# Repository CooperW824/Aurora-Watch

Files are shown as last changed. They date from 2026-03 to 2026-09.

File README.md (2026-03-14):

# Aurora-Watch
Project Aurora: The most over-engineered gimmick ever. A watch that is a compass, thermometer, step-counter, flashlight, all with a rechargable battery, and a processor 50x faster than the Apollo Guidance Computer.

## What is it?

It is a custom designed printed circuit board that contains a ring of 12 RGB LEDs, a microcontroller, and some senors to:
1. Display the current time. Where the red LED represents the hour hand, the green LED is the minute hand and the blue LED is the second hand.
2. Display the current ambient temperature using the number of LEDs lit and the color of the LEDs for the temperature.
3. A magnetic compass with the red LED pointing north, and the blue LED pointing south
4. A read out of the current battery charge using the LEDs
5. A built in step counter
5. A flashlight that uses the red LEDs to create a red-light flashlight
6. Rechargable LiPO battery using USB-C

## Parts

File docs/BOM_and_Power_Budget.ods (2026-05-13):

Component Function | Component Name | Predicted Power Draw (uA) | BOM Cost | Notes | I2C Address
12x LEDs | EAST1616RGBA8 | 650 | $2.63
Microcontroller | STM32U031K8U6 | 83.8 | $4.50
Compass Module | LSM303AGR | 7.7 | $3.41 |  | 0b0011001 / 0b0011110
LED Controller | IS31FL3237 | 0 | $2.81 | (Included in LEDs) | 0b0110100
Temperature Sensor | TMP1075 | 1 | $0.20 |  | 0b1001000
Battery Charge Controller | BQ25185 | 4.5 | $1.93
USB to UART | CP2102N-A02-GQFN20R | 0 | $1.88 | (Only Active When Plugged In)
Battery Fuel Gauge | MAX17048G+T10 | 4 | $2.45 |  | 0b0110110
32.768KHz Crystal | ABS07-32.768KHZ-T | 1 | $0.50
Buck-Boost Converter | TPS63900 | 1 | $1.41
Passives |  | 10 | $6.00
 |  | 763 | $27.72 | Subtotal
 |  | Battery | $7.00
 |  | Board | $3.00
 |  |  | $37.72 | Per Watch
 |  | 2 MOQ | $75.44
 |  | Assembly | $25.00
 |  | Shipping | $40.00
 |  |  | $140.44 | Total

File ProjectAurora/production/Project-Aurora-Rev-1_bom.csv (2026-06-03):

Designator | Footprint | Quantity | Value | LCSC Part #
3V3, GND1, SWCLK1, SWDIO1 | TestPoint_Pad_2.0x2.0mm | 4 | TestPoint
B1, B10, B11, B12, B2, B3, B4, B5, B6, B8, B9, CHARGE_EN1, CHG_ST1, CHG_ST2, CP_RST1, CP_VBUS1, G1, G10, G11, G12, G2, G3, G4, G5, G6, G7, G8, G9, GND2, GND3, GND4, GND5, I2C_SCL1, I2C_SDA1, LB1, LED_SHUT1, MAG_INT1, NRST1, RB1, RED1, RED10, RED11, RED12, RED2, RED3, RED4, RED5, RED6, RED7, RED8, RED9, SOC_ALRT1, UART1_RX1, UART1_TX1, VBAT1, VBUS1, VDC1, XLI2, XLI_1 | TestPoint_Pad_1.0x1.0mm | 59 | TestPoint
B7 | TestPoint_Pad_1.0x1.0mm | 1 | `
BT1 | JST_SH_SM02B-SRSS-TB_1x02-1MP_P1.00mm_Horizontal | 1 | Battery_Cell
C1, C2 | 0603 | 2 | 18pF
C10, C13, C15, C18, C23, C26, C3, C4, C8 | 0603 | 9 | 0.1uF
C11, C12, C5 | 0603 | 3 | 4.7uF
C14, C20, C21, C7 | 0603 | 4 | 1uF
C16, C6 | 0603 | 2 | 0.01uF
C17, C22, C24 | 0603 | 3 | 10uF
C19 | 0603 | 1 | 220nF
C25 | 0603 | 1 | 22uF
C9 | 0603 | 1 | 4.7nF
D1, D10, D11, D12, D2, D3, D4, D5, D6, D7, D8, D9 | XL-1615RGBC-YG | 12 | LED_RGBA
D13, D14 | 0603 | 2 | LED
IC1 | IS31FL3237QFLS4TR | 1 | IS31FL3237-QFLS4-TR
IC2 | LGA-12_2x2mm_P0.5mm | 1 | LSM303AGRTR
IC3 | Texas_DLH0010A_WSON-10-1EP_2.2x2mm_P0.4mm_EP0.9x1.5mm_ThermalVias | 1 | BQ25185DLHR
IC4 | TDFN-8-1EP_2x2mm_P0.5mm_EP0.8x1.2mm | 1 | MAX17048G+T10
IC5 | WSON-10-1EP_2.5x2.5mm_P0.5mm_EP1.2x2mm | 1 | TPS63900DSKR
J1 | USB_C_Receptacle_GCT_USB4105-xx-A_16P_TopMnt_Horizontal | 1 | USB_C_Receptacle_USB2.0_14P
L1 | L_Coilcraft_0805HQ_2012Metric | 1 | 2.2uH
R1, R2, R21 | 0603 | 3 | 10K
R10, R9 | 0603 | 2 | 220
R11 | 0603 | 1 | 3.3K
R12 | 0603 | 1 | 100K
R14 | 0603 | 1 | 18K
R15 | 0603 | 1 | 2K
R18 | 0603 | 1 | 36.5K
R3, R4 | 0603 | 2 | 5.1K
R5 | 0603 | 1 | 1K
R6 | 0603 | 1 | 22.1K
R7 | 0603 | 1 | 47.5K
R8 | 0603 | 1 | 1M
S1, S2 | EVPAA202K | 2 | EVP-AA202K
TH1 | 0603 | 1 | 10K @ 25C, B=3435K
U1 | QFN-32-1EP_5x5mm_P0.5mm_EP3.45x3.45mm | 1 | STM32U031K8Ux
U2 | SiliconLabs_QFN-20-1EP_3x3mm_P0.5mm_EP1.8x1.8mm | 1 | CP2102N-Axx-xQFN20
U3 | Texas_DRT-3 | 1 | TPD2EUSB30A
U4 | WSON-8-1EP_2x2mm_P0.5mm_EP0.9x1.6mm_ThermalVias | 1 | TMP1075DSG
Y1 | ABS07 | 1 | ABS07-32.768KHZ-T

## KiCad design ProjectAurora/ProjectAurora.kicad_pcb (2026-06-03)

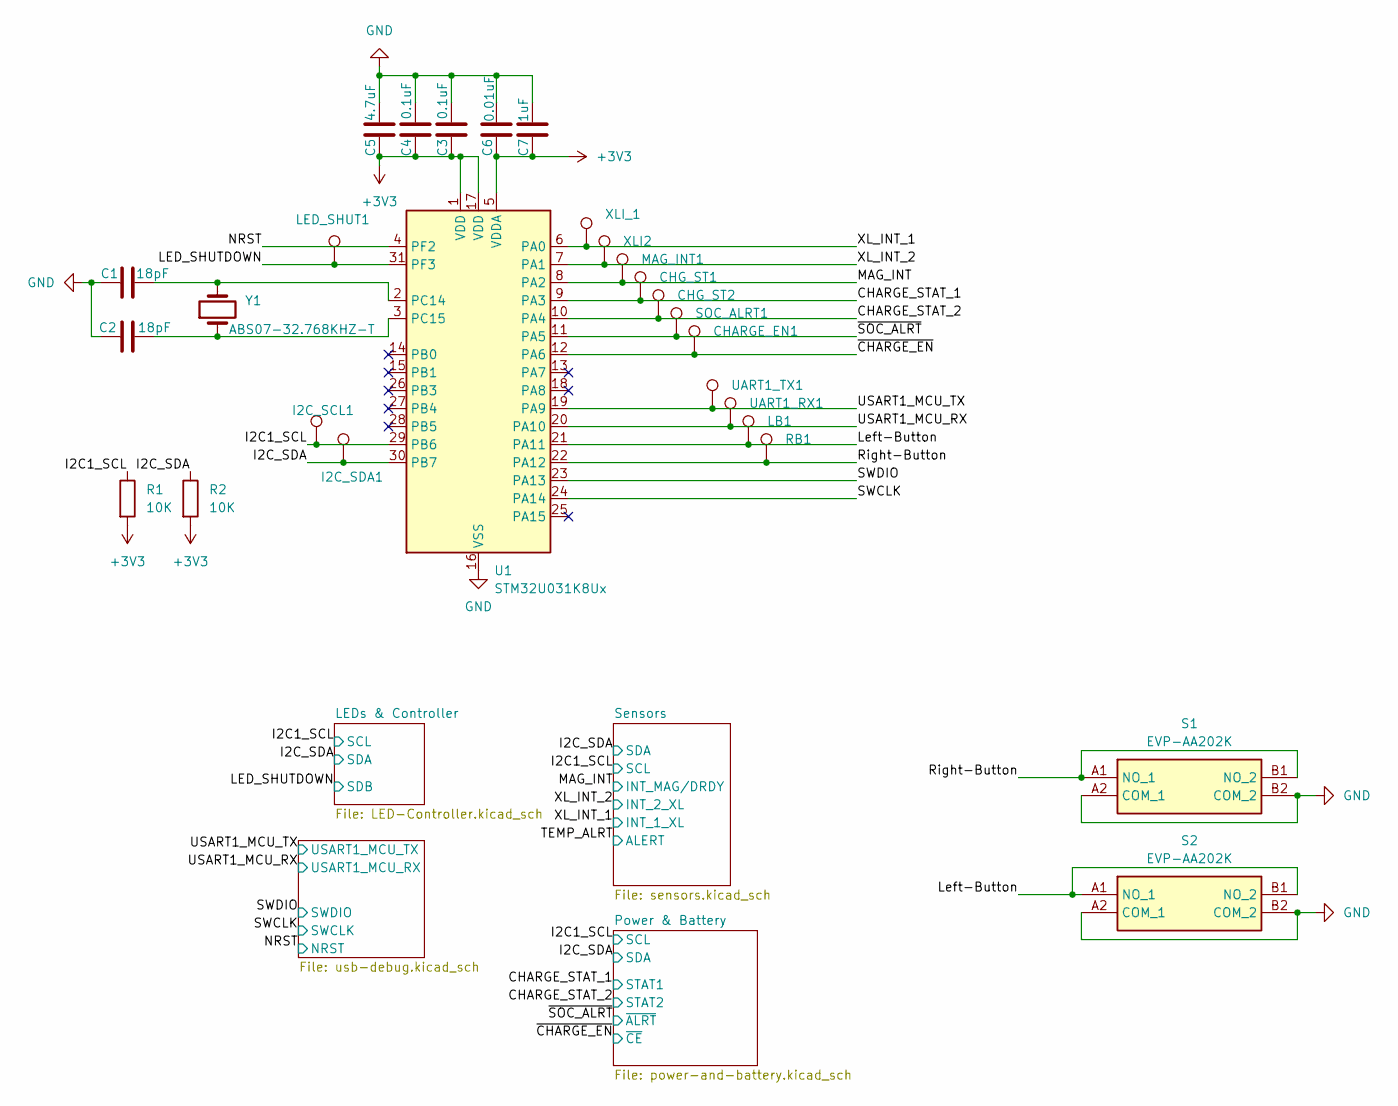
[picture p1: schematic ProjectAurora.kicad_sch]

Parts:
C1, C2: 18pF; C_0603_1608Metric
C3, C4: 0.1uF; C_0603_1608Metric
C5: 4.7uF; C_0603_1608Metric
C6: 0.01uF; C_0603_1608Metric
C7: 1uF; C_0603_1608Metric
CHARGE_EN1: TestPoint; TestPoint_Pad_1.0x1.0mm
CHG_ST1, CHG_ST2: TestPoint; TestPoint_Pad_1.0x1.0mm
I2C_SCL1, I2C_SDA1: TestPoint; TestPoint_Pad_1.0x1.0mm
LB1: TestPoint; TestPoint_Pad_1.0x1.0mm
LED_SHUT1: TestPoint; TestPoint_Pad_1.0x1.0mm
MAG_INT1: TestPoint; TestPoint_Pad_1.0x1.0mm
R1, R2: 10K; R_0603_1608Metric
RB1: TestPoint; TestPoint_Pad_1.0x1.0mm
S1, S2: EVP-AA202K; EVPAA202K; Mouser Part Number 667-EVP-AA202K
SOC_ALRT1: TestPoint; TestPoint_Pad_1.0x1.0mm
U1: STM32U031K8Ux; QFN-32-1EP_5x5mm_P0.5mm_EP3.45x3.45mm
UART1_RX1, UART1_TX1: TestPoint; TestPoint_Pad_1.0x1.0mm
XLI2: TestPoint; TestPoint_Pad_1.0x1.0mm
XLI_1: TestPoint; TestPoint_Pad_1.0x1.0mm
Y1: ABS07-32.768KHZ-T; ABS07

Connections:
+3V3: C3.1, C4.1, C5.1, C6.1, C7.1, R1.2, R2.2, U1.1 (VDD), U1.5 (VDDA), U1.17 (VDD); also elsewhere on the board
/CHARGE_STAT_1: CHG_ST1.1, U1.9 (PA3); also elsewhere on the board
/CHARGE_STAT_2: CHG_ST2.1, U1.10 (PA4); also elsewhere on the board
/I2C1_SCL: I2C_SCL1.1, R1.1, U1.29 (PB6); also elsewhere on the board
/I2C_SDA: I2C_SDA1.1, R2.1, U1.30 (PB7); also elsewhere on the board
/LED_SHUTDOWN: LED_SHUT1.1, U1.31 (PF3); also elsewhere on the board
/Left-Button: LB1.1, S2.A1 (NO_1), S2.B1 (NO_2), U1.21 (PA11)
/MAG_INT: MAG_INT1.1, U1.8 (PA2); also elsewhere on the board
/NRST: U1.4 (PF2); also elsewhere on the board
/Right-Button: RB1.1, S1.A1 (NO_1), S1.B1 (NO_2), U1.22 (PA12)
/SWCLK: U1.24 (PA14); also elsewhere on the board
/SWDIO: U1.23 (PA13); also elsewhere on the board
/USART1_MCU_RX: U1.20 (PA10), UART1_RX1.1; also elsewhere on the board
/USART1_MCU_TX: U1.19 (PA9), UART1_TX1.1; also elsewhere on the board
/XL_INT_1: U1.6 (PA0), XLI_1.1; also elsewhere on the board
/XL_INT_2: U1.7 (PA1), XLI2.1; also elsewhere on the board
/~CHARGE_EN: CHARGE_EN1.1, U1.12 (PA6); also elsewhere on the board
/~SOC_ALRT: SOC_ALRT1.1, U1.11 (PA5); also elsewhere on the board
GND: C1.1, C2.1, C3.2, C4.2, C5.2, C6.2, C7.2, S1.A2 (COM_1), S1.B2 (COM_2), S2.A2 (COM_1), S2.B2 (COM_2), U1.16 (VSS), U1.32 (VSS), U1.33 (VSS); also elsewhere on the board
unnamed: C1.2, U1.2 (PC14), Y1.2
unnamed: C2.2, U1.3 (PC15), Y1.1

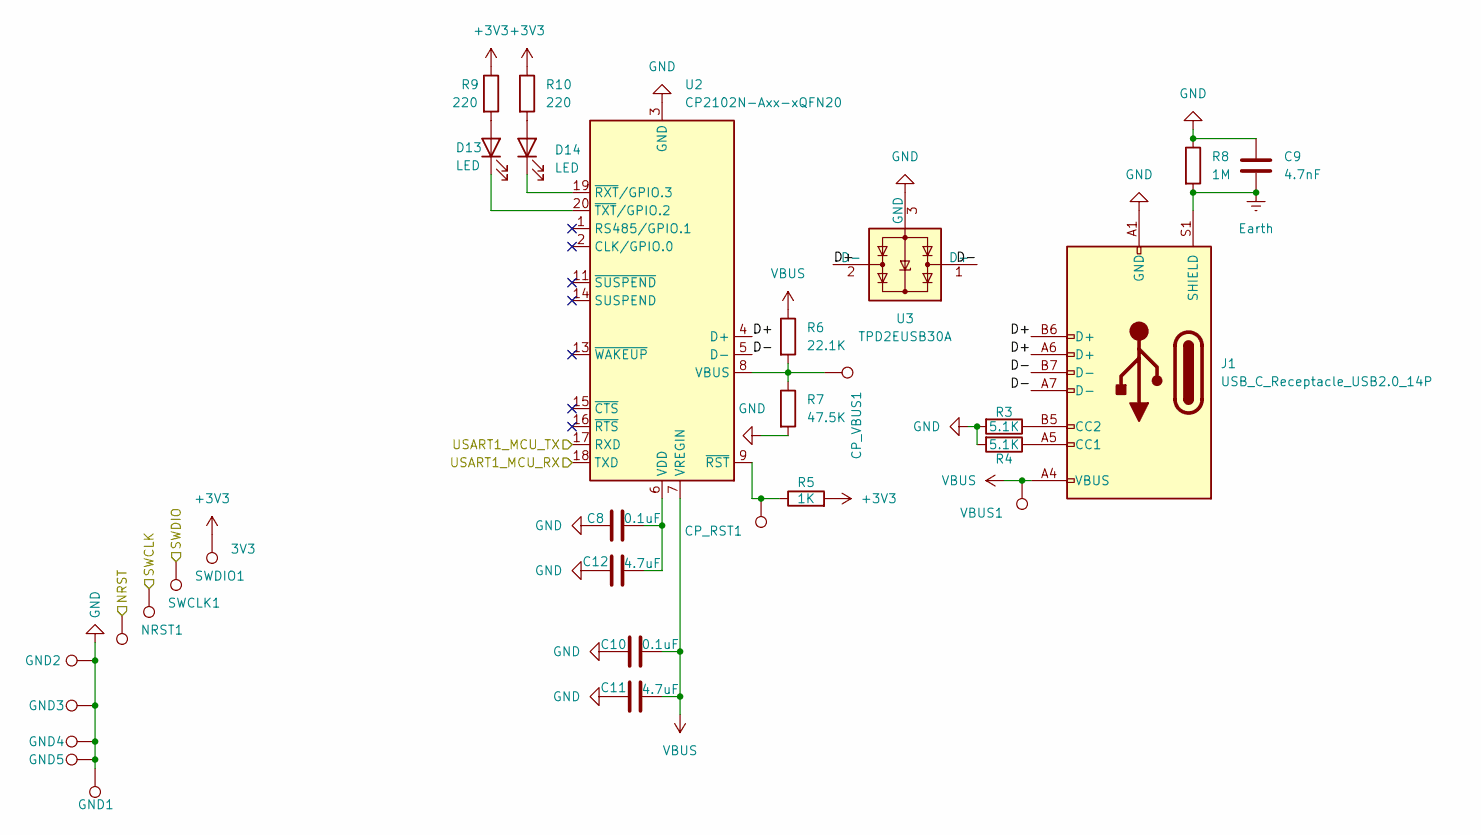
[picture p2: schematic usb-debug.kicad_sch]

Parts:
3V3: TestPoint; TestPoint_Pad_2.0x2.0mm
C8, C10: 0.1uF; C_0603_1608Metric
C9: 4.7nF; C_0603_1608Metric
C11, C12: 4.7uF; C_0603_1608Metric
CP_RST1: TestPoint; TestPoint_Pad_1.0x1.0mm
CP_VBUS1: TestPoint; TestPoint_Pad_1.0x1.0mm
D13, D14: LED; LED_0603_1608Metric
GND1: TestPoint; TestPoint_Pad_2.0x2.0mm
GND2, GND3, GND4, GND5: TestPoint; TestPoint_Pad_1.0x1.0mm
J1: USB_C_Receptacle_USB2.0_14P; USB_C_Receptacle_GCT_USB4105-xx-A_16P_TopMnt_Horizontal
NRST1: TestPoint; TestPoint_Pad_1.0x1.0mm
R3, R4: 5.1K; R_0603_1608Metric
R5: 1K; R_0603_1608Metric
R6: 22.1K; R_0603_1608Metric
R7: 47.5K; R_0603_1608Metric
R8: 1M; R_0603_1608Metric
R9, R10: 220; R_0603_1608Metric
SWCLK1: TestPoint; TestPoint_Pad_2.0x2.0mm
SWDIO1: TestPoint; TestPoint_Pad_2.0x2.0mm
U2: CP2102N-Axx-xQFN20; SiliconLabs_QFN-20-1EP_3x3mm_P0.5mm_EP1.8x1.8mm
U3: TPD2EUSB30A; Texas_DRT-3
VBUS1: TestPoint; TestPoint_Pad_1.0x1.0mm

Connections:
+3V3: 3V3.1, R5.2, R9.1, R10.1; also elsewhere on the board
/NRST: NRST1.1; also elsewhere on the board
/SWCLK: SWCLK1.1; also elsewhere on the board
/SWDIO: SWDIO1.1; also elsewhere on the board
/USART1_MCU_RX: U2.18 (TXD); also elsewhere on the board
/USART1_MCU_TX: U2.17 (RXD); also elsewhere on the board
/USB & Debug/D+: J1.A6 (D+), J1.B6 (D+), U2.4 (D+), U3.2 (D-)
/USB & Debug/D-: J1.A7 (D-), J1.B7 (D-), U2.5 (D-), U3.1 (D+)
Earth: C9.2, J1.S1 (SHIELD), R8.2
GND: C8.1, C9.1, C10.1, C11.1, C12.1, GND1.1, GND2.1, GND3.1, GND4.1, GND5.1, J1.A1 (GND), J1.A12 (GND), J1.B1 (GND), J1.B12 (GND), R3.2, R4.2, R7.2, R8.1, U2.3 (GND), U2.12 (GND), U2.21 (GND), U3.3 (GND); also elsewhere on the board
unnamed: D13.2 (A), R9.2
unnamed: D13.1 (K), U2.20 (~TXT/GPIO.2)
unnamed: D14.2 (A), R10.2
unnamed: D14.1 (K), U2.19 (~RXT/GPIO.3)
unnamed: J1.A5 (CC1), R4.1
unnamed: J1.B5 (CC2), R3.1
unnamed: CP_VBUS1.1, R6.2, R7.1, U2.8 (VBUS)
unnamed: C8.2, C12.2, U2.6 (VDD)
unnamed: CP_RST1.1, R5.1, U2.9 (~RST)
VBUS: C10.2, C11.2, J1.A4 (VBUS), J1.A9 (VBUS), J1.B4 (VBUS), J1.B9 (VBUS), R6.1, U2.7 (VREGIN), VBUS1.1; also elsewhere on the board

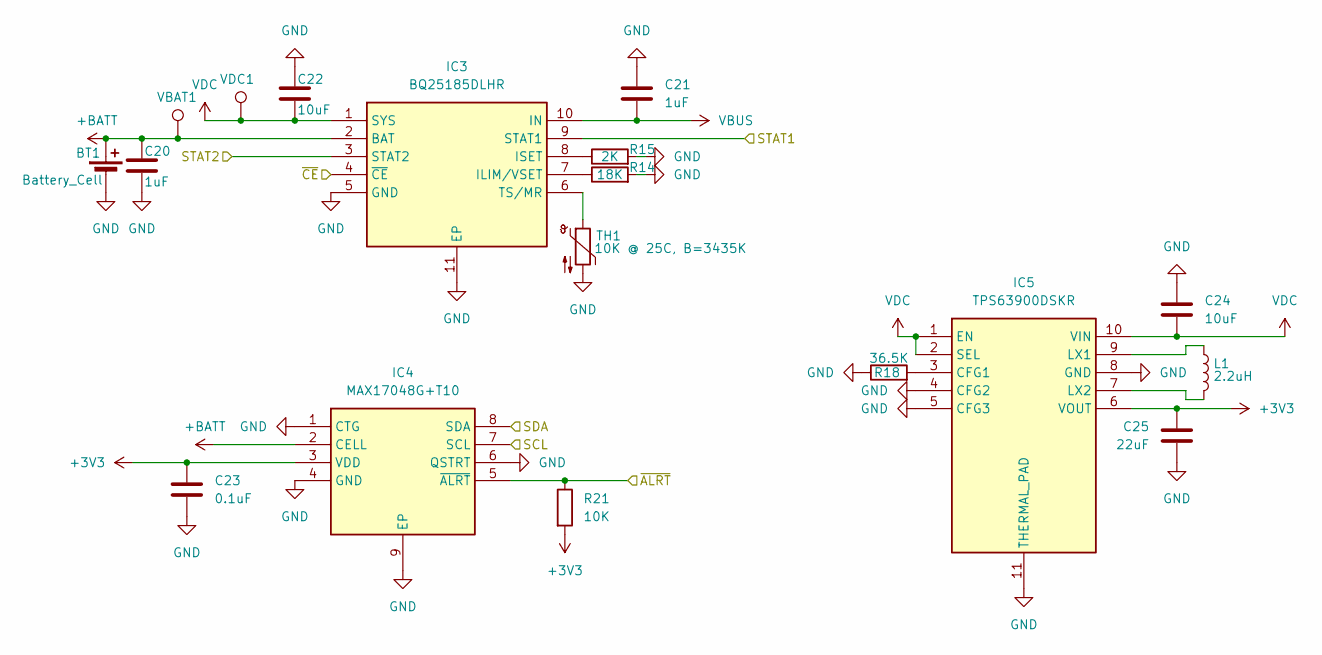
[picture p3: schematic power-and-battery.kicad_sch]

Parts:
BT1: Battery_Cell; JST_SH_SM02B-SRSS-TB_1x02-1MP_P1.00mm_Horizontal
C20, C21: 1uF; C_0603_1608Metric
C22, C24: 10uF; C_0603_1608Metric
C23: 0.1uF; C_0603_1608Metric
C25: 22uF; C_0603_1608Metric
IC3: BQ25185DLHR; Texas_DLH0010A_WSON-10-1EP_2.2x2mm_P0.4mm_EP0.9x1.5mm_Therm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; Mouser Part Number 595-BQ25185DLHR
IC4: MAX17048G+T10; TDFN-8-1EP_2x2mm_P0.5mm_EP0.8x1.2mm; Mouser Part Number 700-MAX17048G+T10
IC5: TPS63900DSKR; WSON-10-1EP_2.5x2.5mm_P0.5mm_EP1.2x2mm; Mouser Part Number 595-TPS63900DSKR
L1: 2.2uH; L_Coilcraft_0805HQ_2012Metric
R14: 18K; R_0603_1608Metric
R15: 2K; R_0603_1608Metric
R18: 36.5K; R_0603_1608Metric
R21: 10K; R_0603_1608Metric
TH1: 10K @ 25C, B=3435K; R_0603_1608Metric
VBAT1: TestPoint; TestPoint_Pad_1.0x1.0mm
VDC1: TestPoint; TestPoint_Pad_1.0x1.0mm

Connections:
+3V3: C23.1, C25.2, IC4.3 (VDD), IC5.6 (VOUT), R21.2; also elsewhere on the board
+BATT: BT1.1 (+), C20.1, IC3.2 (BAT), IC4.2 (CELL), VBAT1.1
/CHARGE_STAT_1: IC3.9 (STAT1); also elsewhere on the board
/CHARGE_STAT_2: IC3.3 (STAT2); also elsewhere on the board
/I2C1_SCL: IC4.7 (SCL); also elsewhere on the board
/I2C_SDA: IC4.8 (SDA); also elsewhere on the board
/~CHARGE_EN: IC3.4 (~CE); also elsewhere on the board
/~SOC_ALRT: IC4.5 (~ALRT), R21.1; also elsewhere on the board
GND: BT1.2 (-), C20.2, C21.1, C22.1, C23.2, C24.1, C25.1, IC3.5 (GND), IC3.11 (EP), IC4.1 (CTG), IC4.4 (GND), IC4.6 (QSTRT), IC4.9 (EP), IC5.4 (CFG2), IC5.5 (CFG3), IC5.8 (GND), IC5.11 (THERMAL_PAD), R14.2, R15.2, R18.1, TH1.2; also elsewhere on the board
unnamed: IC3.7 (ILIM/VSET), R14.1
unnamed: IC3.8 (ISET), R15.1
unnamed: IC3.6 (TS/MR), TH1.1
unnamed: IC5.3 (CFG1), R18.2
unnamed: IC5.9 (LX1), L1.1
unnamed: IC5.7 (LX2), L1.2
VBUS: C21.2, IC3.10 (IN); also elsewhere on the board
VDC: C22.2, C24.2, IC3.1 (SYS), IC5.1 (EN), IC5.2 (SEL), IC5.10 (VIN), VDC1.1

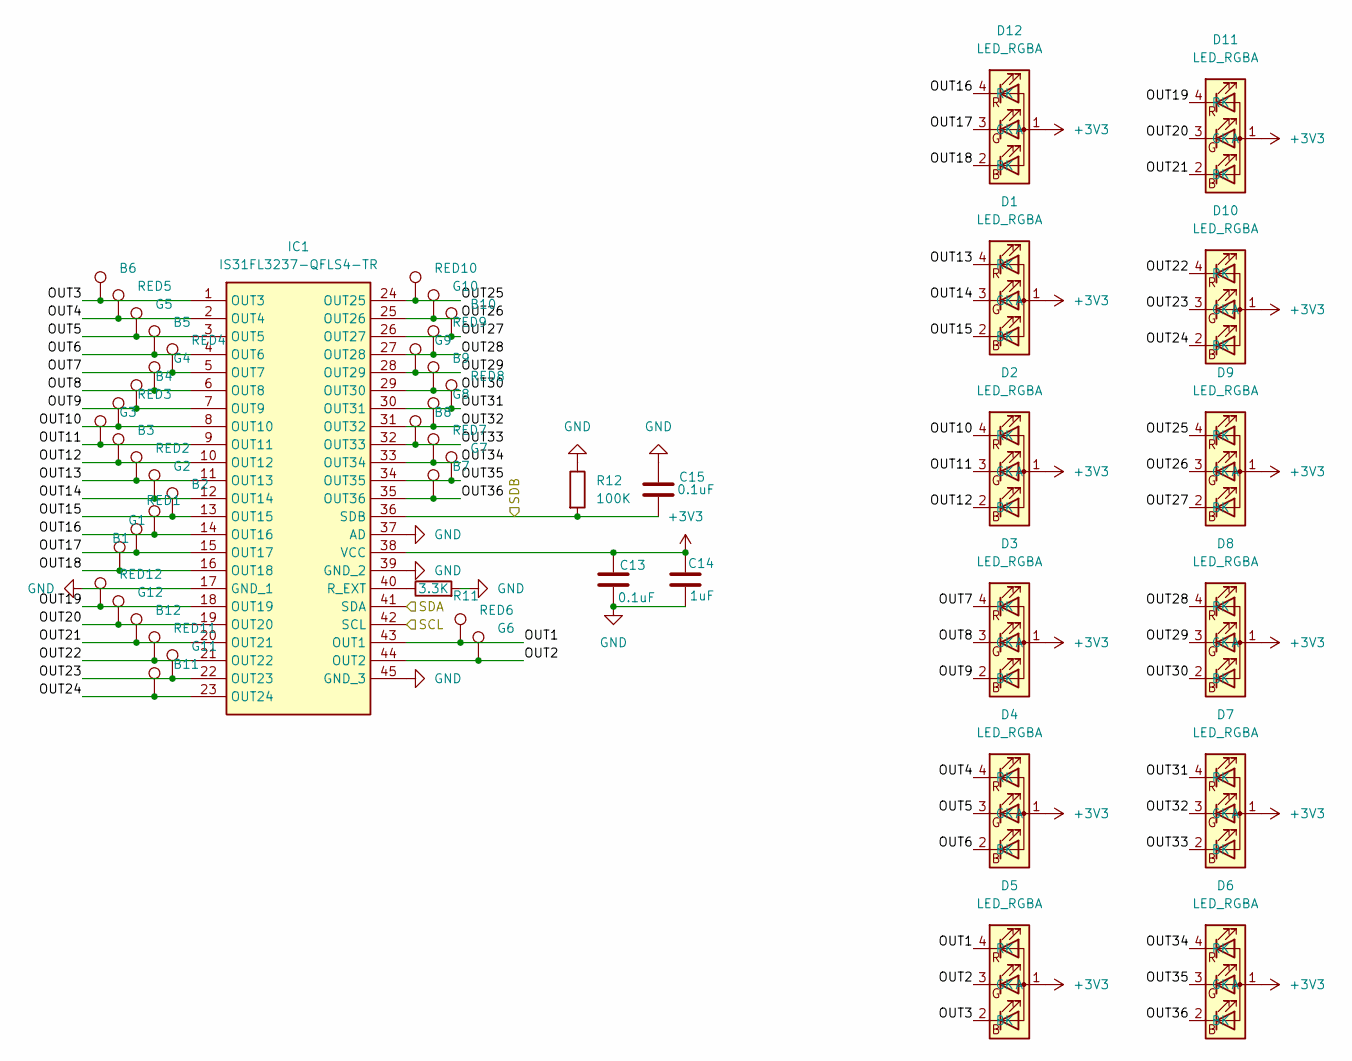
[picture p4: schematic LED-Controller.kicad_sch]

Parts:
B1, B2, B3, B4, B5, B6, B8, B9, B10, B11, B12: TestPoint; TestPoint_Pad_1.0x1.0mm
B7: `; TestPoint_Pad_1.0x1.0mm
C13, C15: 0.1uF; C_0603_1608Metric
C14: 1uF; C_0603_1608Metric
D1, D2, D3, D4, D5, D6, D7, D8, D9, D10, D11, D12: LED_RGBA; XL-1615RGBC-YG
G1, G2, G3, G4, G5, G6, G7, G8, G9, G10, G11, G12: TestPoint; TestPoint_Pad_1.0x1.0mm
IC1: IS31FL3237-QFLS4-TR; IS31FL3237QFLS4TR; Mouser Part Number 870-IS31FL3237QFLS4T
R11: 3.3K; R_0603_1608Metric
R12: 100K; R_0603_1608Metric
RED1, RED2, RED3, RED4, RED5, RED6, RED7, RED8, RED9, RED10, RED11, RED12: TestPoint; TestPoint_Pad_1.0x1.0mm

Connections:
+3V3: C13.1, C14.1, D1.1 (A), D2.1 (A), D3.1 (A), D4.1 (A), D5.1 (A), D6.1 (A), D7.1 (A), D8.1 (A), D9.1 (A), D10.1 (A), D11.1 (A), D12.1 (A), IC1.38 (VCC); also elsewhere on the board
/I2C1_SCL: IC1.42 (SCL); also elsewhere on the board
/I2C_SDA: IC1.41 (SDA); also elsewhere on the board
/LED_SHUTDOWN: C15.2, IC1.36 (SDB), R12.2; also elsewhere on the board
/LEDs & Controller/OUT1: D5.4 (RK), IC1.43 (OUT1), RED6.1
/LEDs & Controller/OUT2: D5.3 (GK), G6.1, IC1.44 (OUT2)
/LEDs & Controller/OUT3: B6.1, D5.2 (BK), IC1.1 (OUT3)
/LEDs & Controller/OUT4: D4.4 (RK), IC1.2 (OUT4), RED5.1
/LEDs & Controller/OUT5: D4.3 (GK), G5.1, IC1.3 (OUT5)
/LEDs & Controller/OUT6: B5.1, D4.2 (BK), IC1.4 (OUT6)
/LEDs & Controller/OUT7: D3.4 (RK), IC1.5 (OUT7), RED4.1
/LEDs & Controller/OUT8: D3.3 (GK), G4.1, IC1.6 (OUT8)
/LEDs & Controller/OUT9: B4.1, D3.2 (BK), IC1.7 (OUT9)
/LEDs & Controller/OUT10: D2.4 (RK), IC1.8 (OUT10), RED3.1
/LEDs & Controller/OUT11: D2.3 (GK), G3.1, IC1.9 (OUT11)
/LEDs & Controller/OUT12: B3.1, D2.2 (BK), IC1.10 (OUT12)
/LEDs & Controller/OUT13: D1.4 (RK), IC1.11 (OUT13), RED2.1
/LEDs & Controller/OUT14: D1.3 (GK), G2.1, IC1.12 (OUT14)
/LEDs & Controller/OUT15: B2.1, D1.2 (BK), IC1.13 (OUT15)
/LEDs & Controller/OUT16: D12.4 (RK), IC1.14 (OUT16), RED1.1
/LEDs & Controller/OUT17: D12.3 (GK), G1.1, IC1.15 (OUT17)
/LEDs & Controller/OUT18: B1.1, D12.2 (BK), IC1.16 (OUT18)
/LEDs & Controller/OUT19: D11.4 (RK), IC1.18 (OUT19), RED12.1
/LEDs & Controller/OUT20: D11.3 (GK), G12.1, IC1.19 (OUT20)
/LEDs & Controller/OUT21: B12.1, D11.2 (BK), IC1.20 (OUT21)
/LEDs & Controller/OUT22: D10.4 (RK), IC1.21 (OUT22), RED11.1
/LEDs & Controller/OUT23: D10.3 (GK), G11.1, IC1.22 (OUT23)
/LEDs & Controller/OUT24: B11.1, D10.2 (BK), IC1.23 (OUT24)
/LEDs & Controller/OUT25: D9.4 (RK), IC1.24 (OUT25), RED10.1
/LEDs & Controller/OUT26: D9.3 (GK), G10.1, IC1.25 (OUT26)
/LEDs & Controller/OUT27: B10.1, D9.2 (BK), IC1.26 (OUT27)
/LEDs & Controller/OUT28: D8.4 (RK), IC1.27 (OUT28), RED9.1
/LEDs & Controller/OUT29: D8.3 (GK), G9.1, IC1.28 (OUT29)
/LEDs & Controller/OUT30: B9.1, D8.2 (BK), IC1.29 (OUT30)
/LEDs & Controller/OUT31: D7.4 (RK), IC1.30 (OUT31), RED8.1
/LEDs & Controller/OUT32: D7.3 (GK), G8.1, IC1.31 (OUT32)
/LEDs & Controller/OUT33: B8.1, D7.2 (BK), IC1.32 (OUT33)
/LEDs & Controller/OUT34: D6.4 (RK), IC1.33 (OUT34), RED7.1
/LEDs & Controller/OUT35: D6.3 (GK), G7.1, IC1.34 (OUT35)
/LEDs & Controller/OUT36: B7.1, D6.2 (BK), IC1.35 (OUT36)
GND: C13.2, C14.2, C15.1, IC1.17 (GND_1), IC1.37 (AD), IC1.39 (GND_2), IC1.45 (GND_3), R11.2, R12.1; also elsewhere on the board
unnamed: IC1.40 (R_EXT), R11.1

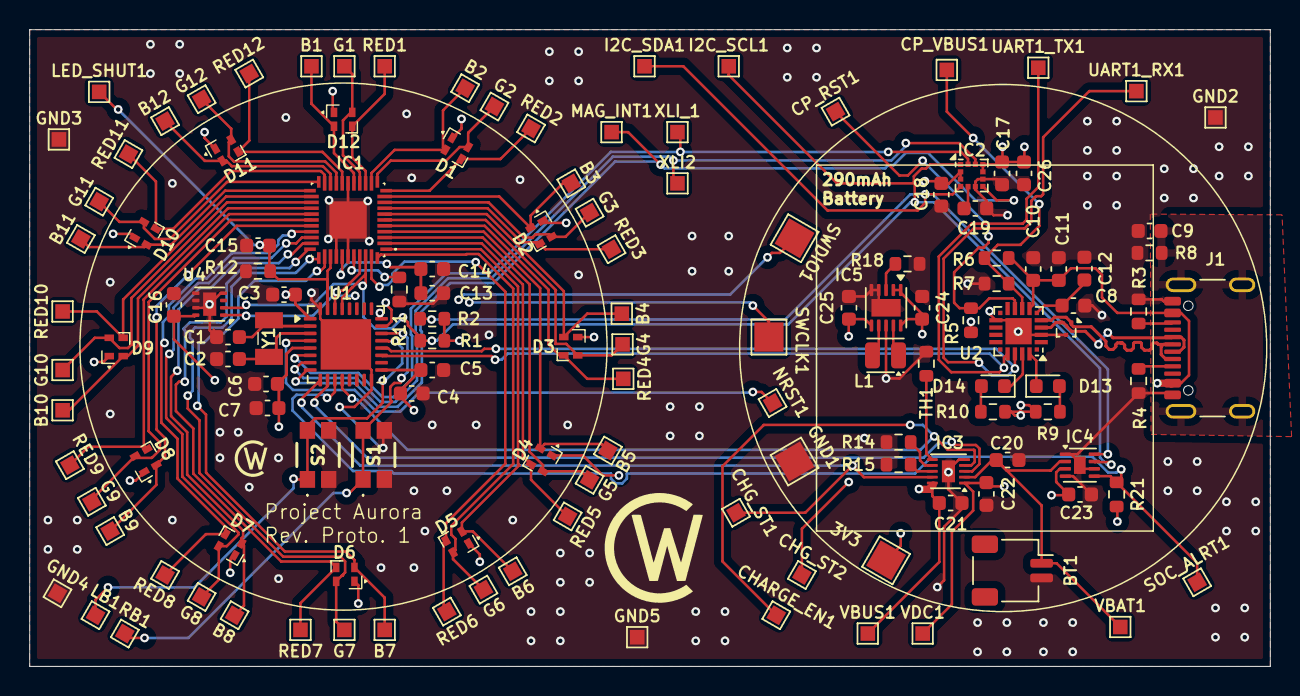
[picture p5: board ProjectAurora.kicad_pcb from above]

Board: 4 copper layers, 84.8 x 43.5 mm, 136 parts (0 on the bottom side), 80 nets.

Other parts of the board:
C16: 0.01uF; C_0603_1608Metric
C17: 10uF; C_0603_1608Metric
C18, C26: 0.1uF; C_0603_1608Metric
C19: 220nF; C_0603_1608Metric
IC2: LSM303AGRTR; LGA-12_2x2mm_P0.5mm
U4: TMP1075DSG; WSON-8-1EP_2x2mm_P0.5mm_EP0.9x1.6mm_ThermalVias

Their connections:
+3V3: C16.2, C17.1, C18.1, C26.1, IC2.2 (CS_XL), IC2.3 (CS_MAG), IC2.9 (VDD), IC2.10 (VDD_IO), U4.8 (V+); also elsewhere on the board
/I2C1_SCL: IC2.1 (SCL/SPC), U4.2 (SCL); also elsewhere on the board
/I2C_SDA: IC2.4 (SDA/SDI/SDO), U4.1 (SDA); also elsewhere on the board
/MAG_INT: IC2.7 (INT_MAG/DRDY); also elsewhere on the board
/XL_INT_1: IC2.12 (INT_1_XL); also elsewhere on the board
/XL_INT_2: IC2.11 (INT_2_XL); also elsewhere on the board
GND: C16.1, C17.2, C18.2, C19.2, C26.2, IC2.6 (GND_1), IC2.8 (GND_2), U4.4 (GND), U4.5 (A2), U4.6 (A1), U4.7 (A0), U4.9 (EP); also elsewhere on the board
unnamed: C19.1, IC2.5 (C1)

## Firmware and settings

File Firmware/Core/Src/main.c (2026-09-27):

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
/* Includes ------------------------------------------------------------------*/
#include "main.h"
#include "is31fl3237.h"
#include "math.h"
#include "stm32u0xx_hal.h"
#include "timekeeping.h"
#include "tmp1075.h"


/* USER CODE BEGIN PD */

#define PWM_INCREMENT 5

/* USER CODE END PD */


I2C_HandleTypeDef hi2c1;

RTC_HandleTypeDef hrtc;

UART_HandleTypeDef huart1;

FL3237_HandleTypeDef fl3237_handle;
FL3237_ControlRegisterConfig fl3237_cr;

TMP1075_HandleTypeDef tmp1075_handle;

uint8_t time_str[9];

void SystemClock_Config(void);
static void MX_GPIO_Init(void);
static void MX_I2C1_Init(void);
static void MX_RTC_Init(void);
static void MX_USART1_UART_Init(void);

void FL3237_Config();
/**
 * @brief  The application entry point.
 * @retval int
 */
int main(void) {

  /* MCU Configuration--------------------------------------------------------*/

  /* Reset of all peripherals, Initializes the Flash interface and the Systick.
   */
  HAL_Init();

  /* Configure the system clock */
  SystemClock_Config();

  /* Initialize all configured peripherals */
  MX_GPIO_Init();
  MX_I2C1_Init();
  MX_RTC_Init();
  MX_USART1_UART_Init();
  /* USER CODE BEGIN 2 */

  FL3237_Config();

  FL3237_SetHardwareChipEnable(&fl3237_handle, FL3237_HARDWARE_CHIP_ENABLE);

  /* USER CODE END 2 */

  // // First we want to get the time from the user, for the demo, this can
  // block
  // // indefinitely
  // HAL_UART_Transmit(&huart1, "Watch Ready", 11, UINT32_MAX);
  // HAL_UART_Receive(&huart1, time_str, 8, UINT32_MAX);
  // time_str[8] = 0; // Null terminator

  // // One we get that time string, we set the RTC with the time
  // TIMEKEEPING_SetRTCFromString(&hrtc, time_str, 8);
  /* Infinite loop */
  /* USER CODE BEGIN WHILE */
  RTC_TimeTypeDef current_time;
  FL3237_RGB_LED watch_face[12];
  while (1) {
    HAL_RTC_GetTime(&hrtc, &current_time, RTC_FORMAT_BIN);

    TIMEKEEPING_TimeToLedPwm(&current_time, watch_face);

    FL3237_BulkSetPWM(&fl3237_handle, 0, watch_face, 12);

    FL3237_UpdatePWM(&fl3237_handle);

    HAL_Delay(5000);
  }
  /* USER CODE END 3 */
}

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
/* USER CODE BEGIN 4 */
void FL3237_Config() {
  fl3237_handle.i2c_bus = &hi2c1;
  fl3237_handle.shutdown_port = LED_SHUTDOWN_GPIO_Port;
  fl3237_handle.shutdown_pin = LED_SHUTDOWN_Pin;
  fl3237_handle.address = FL3237_I2C_AD_TO_GND;
  fl3237_handle.max_transmit_timeout_ms = 100;

  FL3237_Init(&fl3237_handle);
  FL3237_SetGlobalCurrent(&fl3237_handle, 0xFF);
  FL3237_SetAllScaling(
      &fl3237_handle,
      (FL3237_LED_SCALE){.red = 0xFF, .blue = 0xFF, .green = 0xFF});

  fl3237_cr.ssd = FL3237_SSD_CHIP_ENABLE;
  fl3237_cr.pms = FL3237_PMS_8_BIT;
  fl3237_cr.osc = FL3237_OSC_62_KHZ;
  FL3237_SetControlRegister(&fl3237_handle, fl3237_cr);
}

/* USER CODE END 4 */
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


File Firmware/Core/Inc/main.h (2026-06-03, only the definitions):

#define XL_INT_1_Pin GPIO_PIN_0
#define XL_INT_1_GPIO_Port GPIOA
#define XL_INT_2_Pin GPIO_PIN_1
#define XL_INT_2_GPIO_Port GPIOA
#define MAG_INT_Pin GPIO_PIN_2
#define MAG_INT_GPIO_Port GPIOA
#define CHARGE_STAT_1_Pin GPIO_PIN_3
#define CHARGE_STAT_1_GPIO_Port GPIOA
#define CHARGE_STAT_2_Pin GPIO_PIN_4
#define CHARGE_STAT_2_GPIO_Port GPIOA
#define SOC_ALRT_Pin GPIO_PIN_5
#define SOC_ALRT_GPIO_Port GPIOA
#define CHARGE_EN_Pin GPIO_PIN_6
#define CHARGE_EN_GPIO_Port GPIOA
#define LEFT_BUTTON_Pin GPIO_PIN_11
#define LEFT_BUTTON_GPIO_Port GPIOA
#define RIGHT_BUTTON_Pin GPIO_PIN_12
#define RIGHT_BUTTON_GPIO_Port GPIOA
#define LED_SHUTDOWN_Pin GPIO_PIN_3
#define LED_SHUTDOWN_GPIO_Port GPIOF

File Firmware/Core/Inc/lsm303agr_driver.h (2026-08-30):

#ifndef LSM303AGR_DRIVER
#define LSM303AGR_DRIVER

#include "stm32u031xx.h"
#include "stm32u0xx_hal.h"
#include "stm32u0xx_hal_i2c.h"
#include <stdint.h>

#define LSM303_ACCEL_ADDR 0b00110010
#define LSM303_MAG_ADDR 0b00111100

/* ============================================================
 * Register Addresses
 * ============================================================ */

/* --- Accelerometer registers (00h-3Fh) --- */
#define LSM303_REG_STATUS_AUX_A 0x07
#define LSM303_REG_OUT_TEMP_L_A 0x0C
#define LSM303_REG_OUT_TEMP_H_A 0x0D
#define LSM303_REG_INT_COUNTER_A 0x0E
#define LSM303_REG_WHO_AM_I_A 0x0F
#define LSM303_REG_TEMP_CFG_A 0x1F
#define LSM303_REG_CTRL_REG1_A 0x20
#define LSM303_REG_CTRL_REG2_A 0x21
#define LSM303_REG_CTRL_REG3_A 0x22
#define LSM303_REG_CTRL_REG4_A 0x23
#define LSM303_REG_CTRL_REG5_A 0x24
#define LSM303_REG_CTRL_REG6_A 0x25
#define LSM303_REG_REFERENCE_A 0x26
#define LSM303_REG_STATUS_REG_A 0x27
#define LSM303_REG_OUT_X_L_A 0x28
#define LSM303_REG_OUT_X_H_A 0x29
#define LSM303_REG_OUT_Y_L_A 0x2A
#define LSM303_REG_OUT_Y_H_A 0x2B
#define LSM303_REG_OUT_Z_L_A 0x2C
#define LSM303_REG_OUT_Z_H_A 0x2D
#define LSM303_REG_FIFO_CTRL_A 0x2E
#define LSM303_REG_FIFO_SRC_A 0x2F

/* --- Magnetometer registers (40h-6Fh) --- */
#define LSM303_REG_OFFSET_X_L_M 0x45
#define LSM303_REG_OFFSET_X_H_M 0x46
#define LSM303_REG_OFFSET_Y_L_M 0x47
#define LSM303_REG_OFFSET_Y_H_M 0x48
#define LSM303_REG_OFFSET_Z_L_M 0x49
#define LSM303_REG_OFFSET_Z_H_M 0x4A
#define LSM303_REG_WHO_AM_I_M 0x4F
#define LSM303_REG_CFG_REG_A_M 0x60
#define LSM303_REG_CFG_REG_B_M 0x61
#define LSM303_REG_CFG_REG_C_M 0x62
#define LSM303_REG_INT_CTRL_M 0x63
#define LSM303_REG_INT_SOURCE_M 0x64
#define LSM303_REG_INT_THS_L_M 0x65
#define LSM303_REG_INT_THS_H_M 0x66
#define LSM303_REG_STATUS_REG_M 0x67
#define LSM303_REG_OUTX_L_M 0x68
#define LSM303_REG_OUTX_H_M 0x69
#define LSM303_REG_OUTY_L_M 0x6A
#define LSM303_REG_OUTY_H_M 0x6B
#define LSM303_REG_OUTZ_L_M 0x6C
#define LSM303_REG_OUTZ_H_M 0x6D

#define LSM303_WHO_AM_I_A_VALUE 0x33
#define LSM303_WHO_AM_I_M_VALUE 0x40

/* ============================================================
 * CTRL_REG1_A (20h): ODR3 ODR2 ODR1 ODR0 | LPen Zen Yen Xen
 * ============================================================ */
#define LSM303_A_XEN (1U << 0)
#define LSM303_A_YEN (1U << 1)
#define LSM303_A_ZEN (1U << 2)
#define LSM303_A_LPEN (1U << 3)

#define LSM303_A_ODR_POWERDOWN (0x0U << 4)
#define LSM303_A_ODR_1HZ (0x1U << 4)
#define LSM303_A_ODR_10HZ (0x2U << 4)
#define LSM303_A_ODR_25HZ (0x3U << 4)
#define LSM303_A_ODR_50HZ (0x4U << 4)
#define LSM303_A_ODR_100HZ (0x5U << 4)
#define LSM303_A_ODR_200HZ (0x6U << 4)
#define LSM303_A_ODR_400HZ (0x7U << 4)
#define LSM303_A_ODR_1620HZ_LP (0x8U << 4) /* low-power mode only */
#define LSM303_A_ODR_1344HZ (0x9U << 4)    /* HR/Normal; 5376 Hz in LP mode */

/* ============================================================
 * CTRL_REG4_A (23h): BDU BLE FS1 FS0 HR ST1 ST0 SPI_ENABLE
 * ============================================================ */
#define LSM303_A_SPI_ENABLE (1U << 0)
#define LSM303_A_HR (1U << 3)
#define LSM303_A_BLE (1U << 6)
#define LSM303_A_BDU (1U << 7)

#define LSM303_A_ST_NORMAL (0x0U << 1)
#define LSM303_A_ST_0 (0x1U << 1)
#define LSM303_A_ST_1 (0x2U << 1)

#define LSM303_A_FS_2G (0x0U << 4)
#define LSM303_A_FS_4G (0x1U << 4)
#define LSM303_A_FS_8G (0x2U << 4)
#define LSM303_A_FS_16G (0x3U << 4)

/* ============================================================
 * CTRL_REG5_A (24h): BOOT FIFO_EN -- -- LIR_INT1 D4D_INT1 LIR_INT2 D4D_INT2
 * ============================================================ */
#define LSM303_A_D4D_INT2 (1U << 0)
#define LSM303_A_LIR_INT2 (1U << 1)
#define LSM303_A_D4D_INT1 (1U << 2)
#define LSM303_A_LIR_INT1 (1U << 3)
#define LSM303_A_FIFO_EN (1U << 6)
#define LSM303_A_BOOT (1U << 7)

/* ============================================================
 * CFG_REG_A_M (60h): COMP_TEMP_EN REBOOT SOFT_RST LP ODR1 ODR0 MD1 MD0
 * ============================================================ */
#define LSM303_M_COMP_TEMP_EN (1U << 7) /* must be 1 per datasheet note */
#define LSM303_M_REBOOT (1U << 6)
#define LSM303_M_SOFT_RST (1U << 5)
#define LSM303_M_LP (1U << 4)

#define LSM303_M_ODR_10HZ (0x0U << 2)
#define LSM303_M_ODR_20HZ (0x1U << 2)
#define LSM303_M_ODR_50HZ (0x2U << 2)
#define LSM303_M_ODR_100HZ (0x3U << 2)

#define LSM303_M_MODE_CONTINUOUS 0x0U
#define LSM303_M_MODE_SINGLE 0x1U
#define LSM303_M_MODE_IDLE 0x2U /* 0x3 also valid, same as 0x2 */

/* ============================================================
 * CFG_REG_B_M (61h): 000 OFF_CANC_ONE_SHOT INT_on_DataOFF Set_FREQ OFF_CANC LPF
 * ============================================================ */
#define LSM303_M_LPF (1U << 0)
#define LSM303_M_OFF_CANC (1U << 1)
#define LSM303_M_SET_FREQ (1U << 2)
#define LSM303_M_INT_ON_DATAOFF (1U << 3)
#define LSM303_M_OFF_CANC_ONE_SHOT (1U << 4)

/* ============================================================
 * CFG_REG_C_M (62h): 0 INT_MAG_PIN I2C_DIS BDU BLE 0 Self_test INT_MAG
 * ============================================================ */
#define LSM303_M_INT_MAG (1U << 0) /* not in struct; DRDY as digital output */
#define LSM303_M_SELF_TEST (1U << 1)
/* bit 2 reserved, must be 0 */
#define LSM303_M_BLE (1U << 3)
#define LSM303_M_BDU (1U << 4)
#define LSM303_M_I2C_DIS (1U << 5)
#define LSM303_M_INT_MAG_PIN (1U << 6) /* not in struct */

typedef struct {

  // Control Register 1
  uint8_t odr;
  uint8_t low_power;
  uint8_t z_enable;
  uint8_t y_enable;
  uint8_t x_enable;

  // CR2 Skipped: Not Needed

  // CR3 Skipped: Not Needed

  // CR4
  uint8_t block_data_update;
  uint8_t endianess;
  uint8_t scale_selection;
  uint8_t operating_mode;
  uint8_t self_test;
  uint8_t spi_enable;

  // CR5
  uint8_t boot;
  uint8_t fifo_enable;
  // Rest of CR5 Skipped

  // CR6 Skipped: Not needed
} LSM303_AccelConfigTypeDef;

typedef struct {
  // CR1
  uint8_t temperature_compensation_enable;
  uint8_t reboot;
  uint8_t soft_rst;
  uint8_t low_power;
  uint8_t output_data_rate;
  uint8_t mode;

  // CR2
  // The Interupt Configuration bits were skipped

  uint8_t one_shot_offset_cancelation_enable;
  uint8_t set_pulse_frequency;
  uint8_t offset_cancelation_enable;
  uint8_t low_pass_filter_enable;

  // CR3
  // The Interupt Configuration bits were skipped

  uint8_t i2c_disable;
  uint8_t block_data_update;
  uint8_t endianess;
  uint8_t self_test;
} LSM303_MagConfigTypeDef;

typedef struct {
  I2C_HandleTypeDef *i2c_bus;
  uint8_t accel_address;
  uint8_t mag_address;
  LSM303_AccelConfigTypeDef *accel_cfg;
  LSM303_MagConfigTypeDef *mag_cfg;

} LSM303_HandleTypeDef;

typedef struct {
  int16_t x;
  int16_t y;
  int16_t z;
} LSM303_Int16Vec3;

HAL_StatusTypeDef LSM303_Accel_SetControlRegs(LSM303_HandleTypeDef *handle);

HAL_StatusTypeDef LSM303_Accel_Enable(LSM303_HandleTypeDef *handle);
HAL_StatusTypeDef LSM303_Accel_Disable(LSM303_HandleTypeDef *handle);
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

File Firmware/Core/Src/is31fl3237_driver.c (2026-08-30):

#include "is31fl3237_driver.h"
#include "stm32u0xx_hal_gpio.h"
#include "stm32u0xx_hal_i2c.h"
#include <stdint.h>
#include <string.h>

#define HIGH_BYTE_MASK 0xFF00
#define LOW_BYTE_MASK 0x00FF

void FL3237_Init(FL3237_HandleTypeDef *handle) {
  // Set shutdown pin to output and set it high to enable the chip
  HAL_GPIO_WritePin(handle->shutdown_port, handle->shutdown_pin, GPIO_PIN_SET);
}

void FL3237_SetControlRegister(FL3237_HandleTypeDef *handle,
                               FL3237_ControlRegisterConfig crc) {
  uint8_t command = 0x00 | (crc.osc << 4) | (crc.pms << 1) | (crc.ssd);
  HAL_I2C_Mem_Write(handle->i2c_bus, handle->address, 0x00,
                    I2C_MEMADD_SIZE_8BIT, &command, 1,
                    handle->max_transmit_timeout_ms);
}

void FL3237_SetHardwareChipEnable(FL3237_HandleTypeDef *handle,
                                  GPIO_PinState state) {
  HAL_GPIO_WritePin(handle->shutdown_port, handle->shutdown_pin, state);
}

void FL3237_SetPWM(FL3237_HandleTypeDef *handle, uint8_t led_number,
                   FL3237_RGB_LED pwm) {
  // The FL3237 has 72 registers for RGB PWM values, starting at 0x01. Each
  // LED has 6 registers (RL, RH, GL, GH, BL, BH), so the register for a given
  // LED can be calculated as 0x01 + (led_number * 6). This code assumes using
  // 8-bit PWM values, so the high byte for each color is set to 0x00.
  uint8_t data[6] = {
      (pwm.red & LOW_BYTE_MASK),   ((pwm.red & HIGH_BYTE_MASK) >> 8),
      (pwm.green & LOW_BYTE_MASK), ((pwm.green & HIGH_BYTE_MASK) >> 8),
      (pwm.blue & LOW_BYTE_MASK),  ((pwm.blue & HIGH_BYTE_MASK) >> 8)};

  HAL_I2C_Mem_Write(handle->i2c_bus, handle->address, 0x01 + (led_number * 6),
                    I2C_MEMADD_SIZE_8BIT, data, 6,
                    handle->max_transmit_timeout_ms);
}

void FL3237_BulkSetPWM(FL3237_HandleTypeDef *handle, uint8_t start_led,
                       FL3237_RGB_LED *pwms, uint8_t len) {
  uint8_t data[12 * 6];
  for (uint8_t i = 0; i < len; i++) {
    data[(6 * i)] = pwms[i].red & LOW_BYTE_MASK;
    data[(6 * i) + 1] = (pwms[i].red & HIGH_BYTE_MASK) >> 8;
    data[(6 * i) + 2] = pwms[i].green & LOW_BYTE_MASK;
    data[(6 * i) + 3] = (pwms[i].green & HIGH_BYTE_MASK) >> 8;
    data[(6 * i) + 4] = pwms[i].blue & LOW_BYTE_MASK;
    data[(6 * i) + 5] = (pwms[i].blue & HIGH_BYTE_MASK) >> 8;
  }

  HAL_I2C_Mem_Write(handle->i2c_bus, handle->address, 0x01 + (start_led * 6),
                    I2C_MEMADD_SIZE_8BIT, data, len * 6,
                    handle->max_transmit_timeout_ms);
}

FL3237_RGB_LED FL3237_GetPWM(FL3237_HandleTypeDef *handle, uint8_t led_number) {
  uint8_t data[6];

  HAL_I2C_Mem_Read(handle->i2c_bus, handle->address, 0x01 + (led_number * 6),
                   I2C_MEMADD_SIZE_8BIT, data, 6,
                   handle->max_transmit_timeout_ms);

  FL3237_RGB_LED led;
  led.red = data[0] | (data[1] << 8);
  led.green = data[2] | (data[3] << 8);
  led.blue = data[4] | (data[5] << 8);

  return led;
}

void FL3237_UpdatePWM(FL3237_HandleTypeDef *handle) {
  uint8_t command =
      0x00; // Write 0x00 to Register 0x49 to update PWM for all registers.
  HAL_I2C_Mem_Write(handle->i2c_bus, handle->address, 0x49,
                    I2C_MEMADD_SIZE_8BIT, &command, 1,
                    handle->max_transmit_timeout_ms);
}

void FL3237_SetGlobalCurrent(FL3237_HandleTypeDef *handle, uint8_t gcc) {
  HAL_I2C_Mem_Write(handle->i2c_bus, handle->address, 0x6E,
                    I2C_MEMADD_SIZE_8BIT, &gcc, 1,
                    handle->max_transmit_timeout_ms);
}

void FL3237_SetLEDScaling(FL3237_HandleTypeDef *handle, uint8_t led_number,
                          FL3237_LED_SCALE scale) {
  uint8_t data[] = {scale.red, scale.green, scale.blue};
  HAL_I2C_Mem_Write(handle->i2c_bus, handle->address, 0x4A + (led_number * 3),
                    I2C_MEMADD_SIZE_8BIT, data, 3,
                    handle->max_transmit_timeout_ms);
}

FL3237_LED_SCALE FL3237_GetLEDScaling(FL3237_HandleTypeDef *handle,
                                      uint8_t led_number) {
  uint8_t data[3];
  HAL_I2C_Mem_Read(handle->i2c_bus, handle->address, 0x4A + (led_number * 3),
                   I2C_MEMADD_SIZE_8BIT, data, 3,
                   handle->max_transmit_timeout_ms);

  FL3237_LED_SCALE scale;
  scale.red = data[0];
  scale.green = data[1];
  scale.blue = data[2];

  return scale;
}

void FL3237_SetAllScaling(FL3237_HandleTypeDef *handle,
                          FL3237_LED_SCALE scale) {
  uint8_t data[36];
  for (uint8_t i = 0; i < 12; i++) {
    data[i * 3] = scale.red;
    data[i * 3 + 1] = scale.green;
    data[i * 3 + 2] = scale.blue;
  }

  // 4Ah is OUT1's scaling register; 36 consecutive registers cover OUT1..OUT36
  HAL_I2C_Mem_Write(handle->i2c_bus, handle->address, 0x4A,
                    I2C_MEMADD_SIZE_8BIT, data, 36,
                    handle->max_transmit_timeout_ms);
}

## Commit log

2026-03-14 Component Selection and Refining Requirements
    [BOM_and_Power_Budget.ods]
2026-03-25 First Schematics
    [BOM_and_Power_Budget.ods, ProjectAurora.kicad_pcb, ProjectAurora.kicad_sch]
2026-04-04 Sensors and LEDs
    [LED-Controller.kicad_sch, ProjectAurora.kicad_sch, sensors.kicad_sch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]
2026-04-05 Schematic Done
    [BOM_and_Power_Budget.ods, ProjectAurora.kicad_sch, power-and-battery.kicad_sch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]
2026-05-13 Starting Layout
    [BOM_and_Power_Budget.ods, LED-Controller.kicad_sch, ProjectAurora.kicad_pcb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]
2026-05-19 Prototype Board Layout Done
    [LED-Controller.kicad_sch, ProjectAurora.kicad_pcb, ProjectAurora.kicad_sch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]
2026-05-19 Prototype Board Ready for Ordering
    [LED-Controller.kicad_sch, ProjectAurora.kicad_pcb, ProjectAurora.kicad_sch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]
2026-06-03 Setting Up the Firmware
    [Project-Aurora-Rev-1_bom.csv, Project-Aurora-Rev-1_designators.csv, Project-Aurora-Rev-1_positions.csv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]
2026-08-22 LED Driver working!
    [power-and-battery.kicad_sch]
2026-08-23 TMP1075 Driver Working
2026-08-23 going to replace the LED test with a watch demo
    [is31fl3237_driver.c, is31fl3237_driver.h, main.c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]
2026-08-30 Define Accelerometer API
2026-09-27 kicad & cubeMX version bump
2026-09-27 implement the accelerometer portion of the driver

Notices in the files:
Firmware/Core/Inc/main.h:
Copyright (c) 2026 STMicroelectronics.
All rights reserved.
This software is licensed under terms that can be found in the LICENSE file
